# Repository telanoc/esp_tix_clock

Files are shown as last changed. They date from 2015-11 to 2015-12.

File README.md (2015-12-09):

=========================================================================

Module: esp tix clock

Date: 13 November 2015

Author: Pete Cervasio <cervasio@airmail.net>

=========================================================================

This project is a TIX clock running on an ESP-01 module.  Since the I/O
is limited, the two available pins are used for an i2c bus to drive a
port expander.  That handles the 27 LEDs as a 9x3 matrix using a ULN2803
and another transistor for the columns and three transistors to drive
the rows.  The other 4 pins read mostly-useless alarm setting buttons.
If only there was another output to use to drive some kind of alarmy
soundy thing.  Oops.  Perhaps I can modify the code so that it doesn't
send any serial data out, and take over the serial port pins.

So, what's a TIX clock?  Google is your friend, as are Bing and Yahoo.
And Youtube to an extent.

Features:

    ESP-01 module gets time from NTP - All you set is the access point
    & password.  You set the timezone before you compile.  Automatic
    changeover takes over from there.  Just don't move around a lot.
    :)

    Power is +5v, regulated to +3.3 for the ESP-01.  The clock in my
    living room is powered by your generic three-for-a-dollar USB
    power brick.

    Time library used to get NTP.  Modifications were made to make the
    time setting closer to msec accuracy (it's pretty close).  I got
    this from https://github.com/PaulStoffregen/Time if you want the
    original.

    WiFiManager used to auto-connect to the access point, and to set
    up the connection if necessary.  From AlexT
    (https://github.com/tzapu) but custom changes are stored in this
    repository.

    Timezone library (https://github.com/JChristensen/Timezone) used
    to handle automatic DST change.

    Display and Controller boards designed in Eagle 7.4 are included.
    The two boards are shared on Osh Park

        Display: https://www.oshpark.com/shared_projects/UMcsDmIr
     Controller: https://www.oshpark.com/shared_projects/IgKxO56E

    An alarm time can be set, but "oops, I need more pins"... there's
    no alarm output.  So it's not much of a feature after all.  As
	noted above, it should be possible to drop the serial port bits
	and take over those pins to be more gpio.

    A dumb 3d printed case will eventually be available on Tinkercad
    or Thingiverse or somewhere.  The one I have started is close but
    not quite there yet.

Caveats and whatnot:

    This was built using staging release esp8266-1.6.5-1160-gef26c5f

    Soldering SMTs by hand is a pain in the behind when you're older.

    Don't bring pin 9 of the display board to +5v without a current
    limiting resistor or you'll take out the 2n3904.  Don't ask how I
    know that...  the resistor on the control board should have been
    moved.
    
    ... ahh hindsight.

    male Power pins are long out the bottom of the control board to
    allow attaching a header for +5v.  That's how I did it.  If you
    have a better idea, please use it.  :)

Todo:

    Build a nice 3d printed case at the North Richland Hills Library
    Maker Spot.  I can't say enough good things about the most
    important building in NRH (and the highly important room upstairs
    that has all the fun makey bits in it).  If you live around Fort
    Worth, go visit.  It's a "soft" maker space, with no table saws or
    welder or whatnot, but that's what the Dallas maker space is good
    for.  :)

    Revamp the boards to bring out serial data, which would allow for
    setting more parameters and storing them in eeprom, like time zone
    values and stuff like that.

    Move that transistor base resistor to the display board.

Harware BOM:  This should be pretty accurate.

        1 - ESP-01
        1 - mcp23017 (so28w)
        1 - uln2803  (so18w)
        4 - MMBT3904 (sot23-bec)
        2 - BSS138 mosfets (sot-23)
        4 - standard through-hole tactile switches
        1 - AP2112K-3.3 regulator (sot-23-5)
        1 - 10uf 0805 capacitor
        2 - 0.1 uf 0805 capacitor
        1 - 1k 0805 resistor
        6 - 10k 0805 resistor
       27 - 68 ohm 0805 resistors
        3 - AA2214SURSK SMT blue LEDs
        6 - yellow SMT LEDs
        9 - red SMT LEDs
        9 - green SMT LEDs
        1 - 1x2 pin male header (extra long) 
        1 - 1x3 pin male header
        1 - 1x3 pin male header
        1 - 1x3 female header
        1 - 1x2 female header
        1 - 1x9 female header
        1 - 2x4 female header

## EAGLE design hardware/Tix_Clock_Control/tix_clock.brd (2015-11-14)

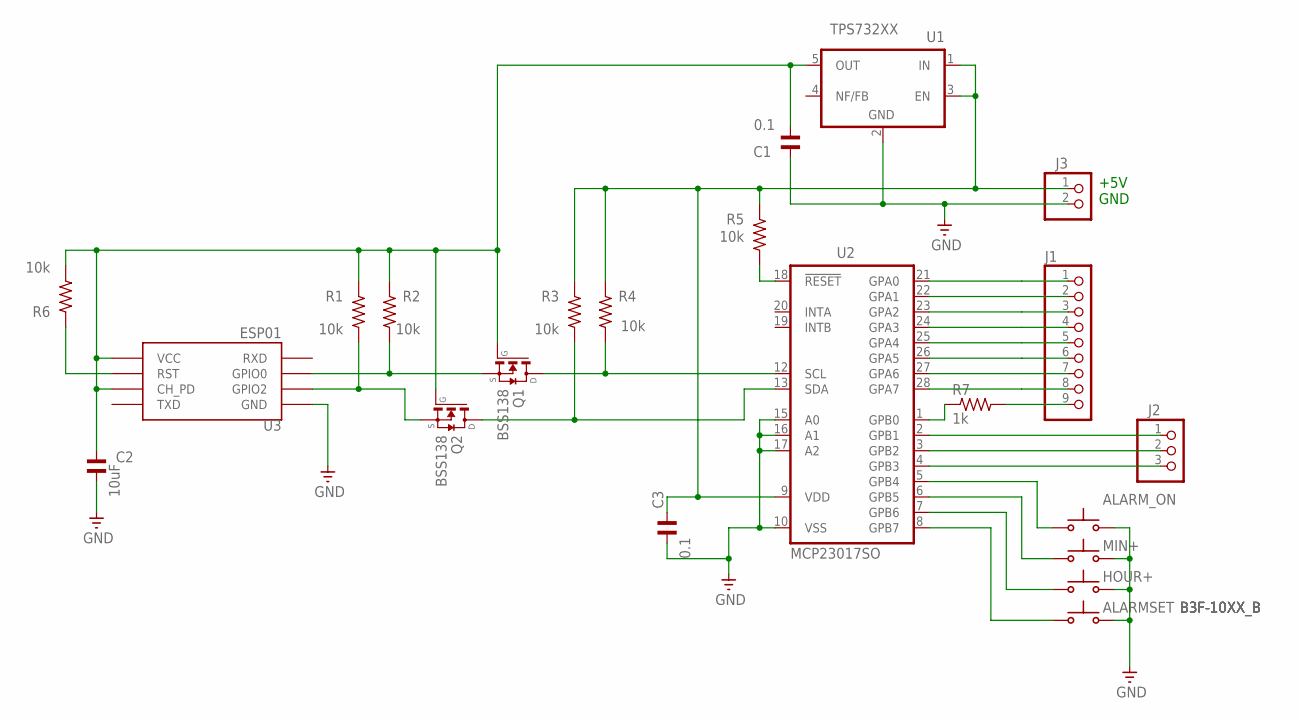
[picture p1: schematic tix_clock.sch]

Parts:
ALARMSET: B3F-10XX_B
ALARM_ON: B3F-10XX_B
C1, C3: 0.1; C0805
C2: 10uF; C0805
HOUR+: B3F-10XX_B
J1: PINHD-1X9; 1X09
J2: PINHD-1X3; 1X03
J3: PINHD-1X2; 1X02
MIN+: B3F-10XX_B
Q1, Q2: BSS138; SOT23
R1, R2, R3, R4, R5, R6: 10k; R0805
R7: 1k; R0805
U1: TPS732XX; SOT23-5
U2: MCP23017SO; SO28W
U3: ESP01

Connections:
GND: ALARMSET.3 (S), ALARMSET.4 (S), ALARM_ON.3 (S), ALARM_ON.4 (S), C1.2, C2.2, C3.2, HOUR+.3 (S), HOUR+.4 (S), J3.2, MIN+.3 (S), MIN+.4 (S), U1.2 (GND), U2.10 (VSS), U2.15 (A0), U2.16 (A1), U2.17 (A2), U3.GND
unnamed: J1.1, U2.21 (GPA0)
unnamed: J1.2, U2.22 (GPA1)
unnamed: J1.3, U2.23 (GPA2)
unnamed: J1.4, U2.24 (GPA3)
unnamed: J1.5, U2.25 (GPA4)
unnamed: J1.6, U2.26 (GPA5)
unnamed: J1.7, U2.27 (GPA6)
unnamed: J1.8, U2.28 (GPA7)
unnamed: J1.9, R7.2
unnamed: J2.1, U2.2 (GPB1)
unnamed: J2.2, U2.3 (GPB2)
unnamed: J2.3, U2.4 (GPB3)
unnamed: ALARM_ON.1, ALARM_ON.2, U2.5 (GPB4)
unnamed: MIN+.1, MIN+.2, U2.6 (GPB5)
unnamed: HOUR+.1, HOUR+.2, U2.7 (GPB6)
unnamed: ALARMSET.1, ALARMSET.2, U2.8 (GPB7)
unnamed: R7.1, U2.1 (GPB0)
unnamed: Q1.3 (D), R4.1, U2.12 (SCL)
unnamed: Q2.3 (D), R3.1, U2.13 (SDA)
unnamed: Q1.2 (S), R2.1, U3.GPIO0
unnamed: Q2.2 (S), R1.1, U3.GPIO2
unnamed: R5.1, U2.18 (!RESET)
unnamed: R6.1, U3.RST
VCC: C1.1, C2.1, Q1.1 (G), Q2.1 (G), R1.2, R2.2, R6.2, U1.5 (OUT), U3.CH_PD, U3.VCC
VDD: C3.1, J3.1, R3.2, R4.2, R5.2, U1.1 (IN), U1.3 (EN), U2.9 (VDD)

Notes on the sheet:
+5V GND

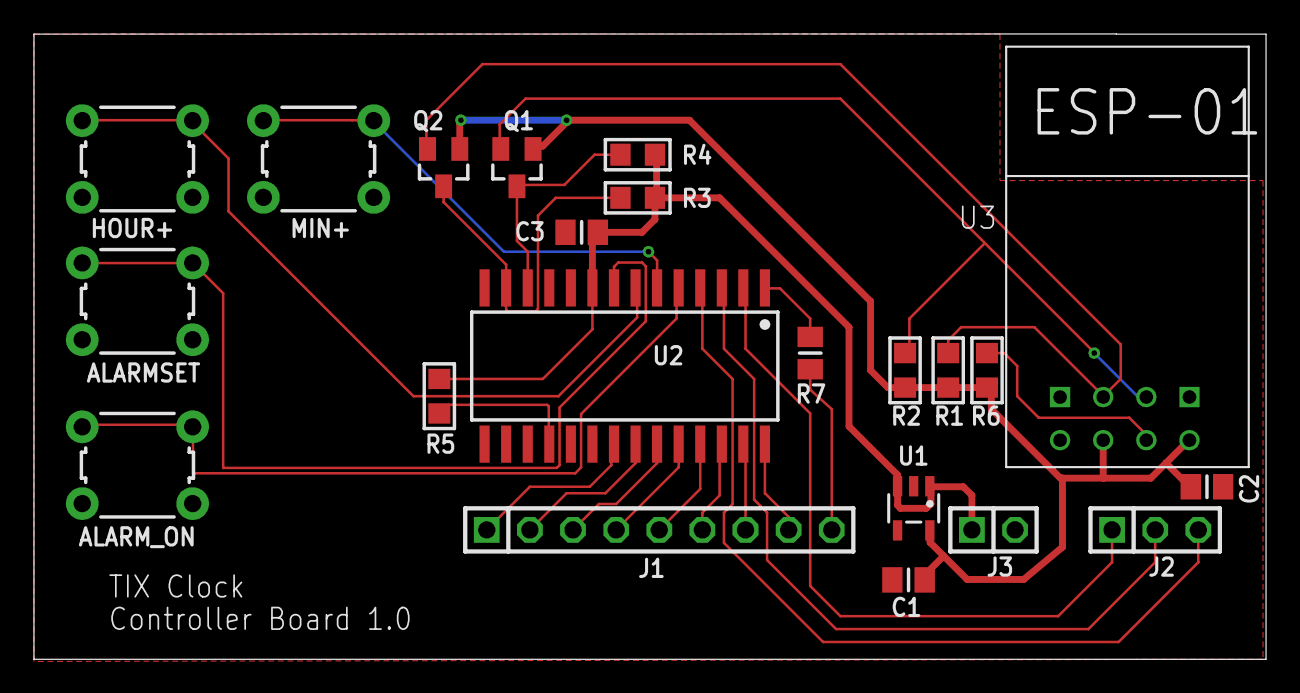
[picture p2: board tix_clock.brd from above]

Board: 2 copper layers, 72.6 x 36.8 mm, 22 parts (0 on the bottom side), 26 nets.

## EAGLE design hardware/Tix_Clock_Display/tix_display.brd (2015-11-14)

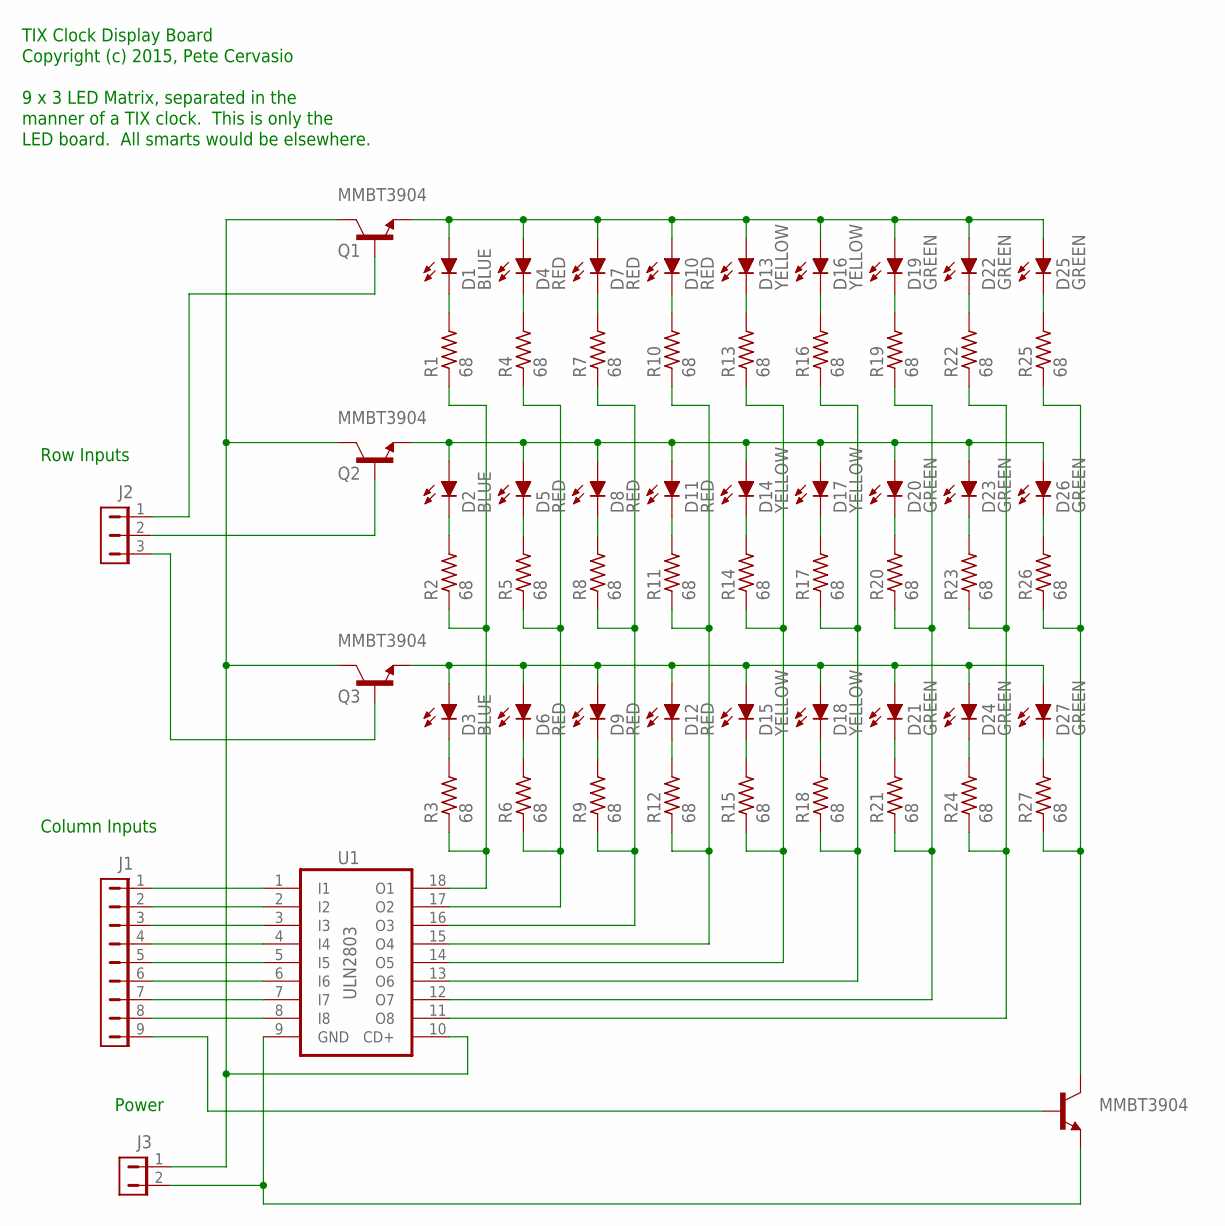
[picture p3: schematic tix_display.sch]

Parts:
D1, D2, D3: BLUE; AA2214SURSK
D4, D5, D6, D7, D8, D9, D10, D11, D12: RED; AA2214SURSK
D13, D14, D15, D16, D17, D18: YELLOW; AA2214SURSK
D19, D20, D21, D22, D23, D24, D25, D26, D27: GREEN; AA2214SURSK
J1: MTA09-100
J2: MTA03-100
J3: MTA02-100
Q1, Q2, Q3, Q4: MMBT3904; SOT23-BEC
R1, R2, R3, R4, R5, R6, R7, R8, R9, R10, R11, R12, R13, R14, R15, R16, R17, R18, R19, R20, R21, R22, R23, R24, R25, R26, R27: 68; M0805
U1: ULN2803; SO18W

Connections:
GND: J3.2, Q4.E, U1.9 (GND)
LEDCOL1: R1.1, R2.1, R3.1, U1.18 (O1)
LEDCOL2: R4.1, R5.1, R6.1, U1.17 (O2)
LEDCOL3: R7.1, R8.1, R9.1, U1.16 (O3)
LEDCOL4: R10.1, R11.1, R12.1, U1.15 (O4)
LEDCOL5: R13.1, R14.1, R15.1, U1.14 (O5)
LEDCOL6: R16.1, R17.1, R18.1, U1.13 (O6)
LEDCOL7: R19.1, R20.1, R21.1, U1.12 (O7)
LEDCOL8: R22.1, R23.1, R24.1, U1.11 (O8)
LEDCOL9: Q4.C, R25.1, R26.1, R27.1
unnamed: D1.A, D4.A, D7.A, D10.A, D13.A, D16.A, D19.A, D22.A, D25.A, Q1.E
unnamed: D2.A, D5.A, D8.A, D11.A, D14.A, D17.A, D20.A, D23.A, D26.A, Q2.E
unnamed: D3.A, D6.A, D9.A, D12.A, D15.A, D18.A, D21.A, D24.A, D27.A, Q3.E
unnamed: D3.C, R3.2
unnamed: D27.C, R27.2
unnamed: J2.1, Q1.B
unnamed: D24.C, R24.2
unnamed: J2.2, Q2.B
unnamed: D21.C, R21.2
unnamed: D18.C, R18.2
unnamed: D15.C, R15.2
unnamed: D12.C, R12.2
unnamed: D9.C, R9.2
unnamed: D6.C, R6.2
unnamed: D2.C, R2.2
unnamed: D5.C, R5.2
unnamed: D8.C, R8.2
unnamed: D11.C, R11.2
unnamed: D14.C, R14.2
unnamed: D17.C, R17.2
unnamed: D20.C, R20.2
unnamed: D23.C, R23.2
unnamed: D26.C, R26.2
unnamed: D1.C, R1.2
unnamed: D25.C, R25.2
unnamed: D22.C, R22.2
unnamed: D19.C, R19.2
unnamed: D16.C, R16.2
unnamed: D13.C, R13.2
unnamed: D10.C, R10.2
unnamed: D7.C, R7.2
unnamed: D4.C, R4.2
unnamed: J2.3, Q3.B
unnamed: J1.1, U1.1 (I1)
unnamed: J1.2, U1.2 (I2)
unnamed: J1.3, U1.3 (I3)
unnamed: J1.4, U1.4 (I4)
unnamed: J1.5, U1.5 (I5)
unnamed: J1.6, U1.6 (I6)
unnamed: J1.7, U1.7 (I7)
unnamed: J1.8, U1.8 (I8)
unnamed: J1.9, Q4.B
VCC: J3.1, Q1.C, Q2.C, Q3.C, U1.10 (CD+)

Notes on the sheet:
Row Inputs
Column Inputs
Power
TIX Clock Display Board Copyright (c) 2015, Pete Cervasio 9 x 3 LED Matrix, separated in the manner of a TIX clock. This is only the LED board. All smarts would be elsewhere.

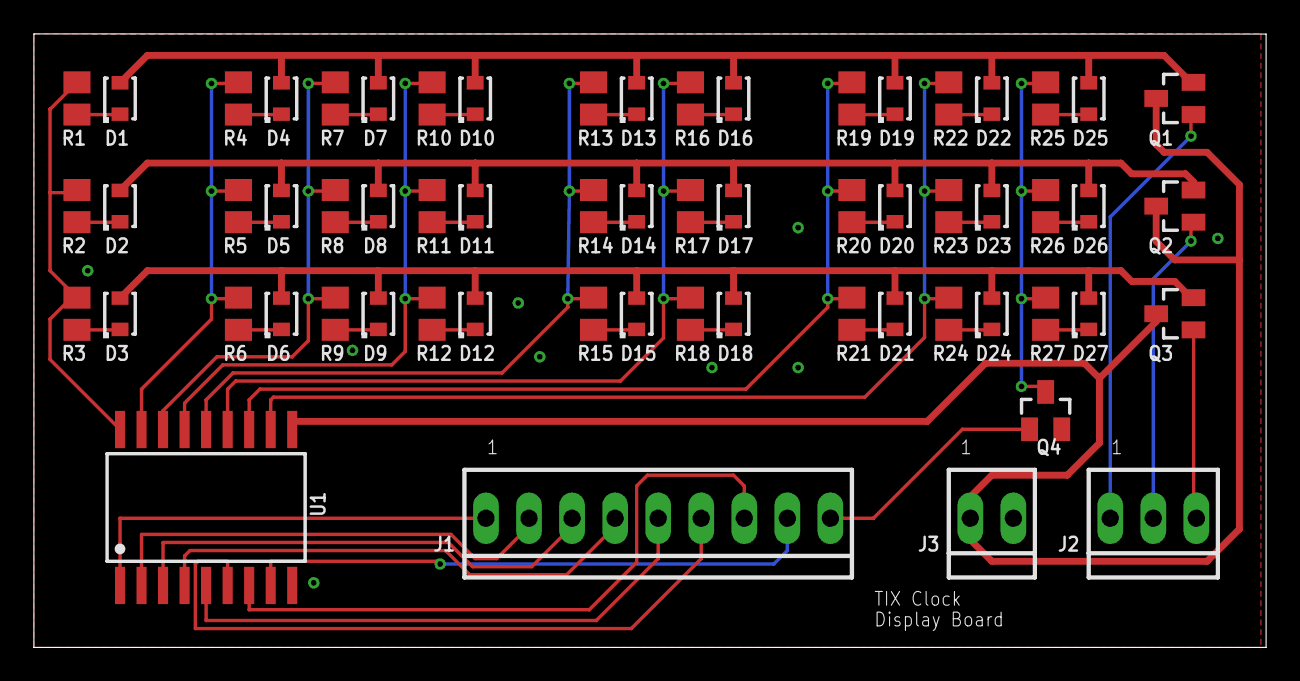
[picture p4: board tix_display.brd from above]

Board: 2 copper layers, 72.7 x 36.2 mm, 62 parts (0 on the bottom side), 53 nets.

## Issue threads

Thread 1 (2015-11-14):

Rev 2 display board needed

telanoc, 2015-11-14:
Existing clock is nice, but tiny.  Need to do a 2nd display board that doesn't have the LEDs mounted, but rather through-holes so external front-panelly kind of LEDs can be attached, for a big TIX clock.

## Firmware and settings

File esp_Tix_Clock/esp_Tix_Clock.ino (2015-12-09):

/*
 * =======================================================================
 * ESP-01 TIX clock
 *
 * Author: Pete Cervasio <cervasio@airmail.net>
 * Date  : 21 SEP 2015
 * 
 * Module: This is a TIX clock using the ESP8266 WiFi chip, in the
 * form of the ESP-01 module.  Since there are only two digital
 * I/O pins available, the options for controlling 27 LEDs are
 * somewhat limited.
 *
 * In this case, we are talking to an MCP23017 16 bit port expander.  It
 * is accessed using gpio0 as the clock line and gpio2 as the data line.
 * The base address of 0x20 is being used.
 * 
 * Bits 0-7 of port A, and bit 0 of port B are being used as column bits
 * while bits 1, 2 and 3 of port B are being used as the row bits.  As
 * there is no PWM control, there is no brightness adjustment.
 * 
 * Bits 4-7 of port B are used as inputs to read 4 switches.  Alarm On
 * toggle, Alarm Set, Alarm Hour+ and Alarm Minute+.
 *
 * Clock logic:
 *
 * The time is retrieved via NTP to 'pool.us.ntp.org'.  A new server is
 * requested any time no response is received from the old server.  The 
 * time server is requeried after one minute at start, which changes to
 * to once per five minutes * successful queries (up to 30 minutes).
 * This is a simple NTP app that doesn't deal with drift.  Whatever the
 * ntp server says the time is, that's what is displayed.
 * 
 * The Time.cpp library is slightly modified to provide a way to set the
 * initial millisecond of the time.  The sync provider callback uses a
 * unsigned long * msec parameter to pass that in.  This makes the clock
 * setting very much more accurate than without, where it can be up to
 * 999 msec off.  When comparing to the time displayed by my NTP synced 
 * Linux desktop, the time changes appear simultaneous.
 * 
 * The WiFiManager library is used to make WiFi setup painless.  The
 * access point and password get stored in eeprom.  If the device can't
 * connect at startup, it sets up a web server on 192.168.4.1 which can
 * be connected to and used to set up the wifi parameters.  This was
 * also modified to 
 * 
 * The Timezone library works with Time and makes DST painless.
 * 
 * At power on, after display test if AlarmSet, Hour+ and Min+ are down, 
 * the current wifi settings are cleared.  Noted by a LED chase display.
 * 
 * TODO: Save alarm time to EEPROM
 *       Work out how to have an alarm beeper (out of pins!)
 *
 * TODO DONE:
 *
 *      Code is at https://github.com/telanoc/esp_tix_clock
 *
 *      Boards at https://www.oshpark.com/shared_projects/UMcsDmIr
 *                https://www.oshpark.com/shared_projects/IgKxO56E
 * 
 * ----------------------------------------------------------------------
 */

#include <ESP8266WiFi.h>        // https://github.com/esp8266/Arduino
#include <EEPROM.h>
#include <ESP8266WebServer.h>
#include <DNSServer.h>
#include <WiFiManager.h>        // https://github.com/tzapu/WiFiManager
#include <WiFiUdp.h>
#include <Wire.h>

// NOTE: Time library modified to pass in partial seconds from UDP packet receive
#include <Time.h>
#include <Timezone.h>

#define TIX_DEBUG

// ESP pins we will use to talk to the i2c bus.  Clock is on
// GPIO0 and data is on GPIO2.
#define SCL_PIN 0
#define SDA_PIN 2

// Address of the MCP23017 i2c port expander on the i2c bus
// This project uses the base address.
#define mcp23017 0x20

// MCP23017 control register definitions
#define REG_MCP_IODIRA   0x00
#define REG_MCP_IODIRB   0x01
#define REG_MCP_IPOLA    0x02
#define REG_MCP_IPOLB    0x03
#define REG_MCP_GPINTENA 0x04
#define REG_MCP_GPINTENB 0x05
#define REG_MCP_DEFVALA  0x06
#define REG_MCP_DEFVALB  0x07
#define REG_MCP_INTCONA  0x08
#define REG_MCP_INTCONB  0x09
#define REG_MCP_IOCONA   0x0A
#define REG_MCP_IOCON    REG_MCP_IOCONA
#define REG_MCP_IOCONB   0x0B
#define REG_MCP_GPPUA    0x0C
#define REG_MCP_GPPUB    0x0D
#define REG_MCP_INTFA    0x0E
#define REG_MCP_INTFB    0x0F
#define REG_MCP_INTCAPA  0x10
#define REG_MCP_INTCAPB  0x11
#define REG_MCP_GPIOA    0x12
#define REG_MCP_GPIOB    0x13
#define REG_MCP_OLATA    0x14
#define REG_MCP_OLATB    0x15

WiFiManager wifi;
unsigned int localPort = 12525;

IPAddress timeServerIP;
const char *ntpServerName = "us.pool.ntp.org";

WiFiUDP udp;

// If this was a good clock, it'd have every timezone defined and let you pick
// which one you wanted during access point setup.  Guess what... this clock
// isn't 100% good.

//US Central Time Zone (Chicago, Dallas, etc)
// Format: Name, which, day of week, month, hour to change, new offset from utc
TimeChangeRule usCDT = {"CDT", Second, dowSunday, Mar, 2, -300};
TimeChangeRule usCST = {"CST", First, dowSunday, Nov, 2, -360};
Timezone myTZ(usCDT, usCST);
TimeChangeRule *tcr;

int lastHour = -1;
int lastMin  = -1;

time_t lastnow = 0;
time_t utc = 0;
time_t local = 0;

int alarm_hour = 12;
int alarm_minute = 34;

// State of ALARM_SET button
bool showing_alarm = false;

// some globals to store our last hour+/min+ button states
bool lastminp = false;
bool lasthourp = false;

// After read/shift, these are the button bits
#define BIT_ALARM_ON      0
#define BIT_MINUTE_PLUS   1
#define BIT_HOUR_PLUS     2
#define BIT_ALARM_SET     3

// Clock display related time values
#define ROWCOUNT 3
#define COLCOUNT 9

// Bits for the columns of each of the 3 rows
unsigned int LedWords[ROWCOUNT] = { 0, 0, 0 };
// values or'd to turn on row driver transistors
unsigned int rowbits[ROWCOUNT] = { 0x0200, 0x0400, 0x0800 };

unsigned long last_ms = 0;
unsigned long last_update = 0;

int ntp_good_count = 0;

int cur_row = 0;

// These should really be named i2c_read... and i2c_write... as they're
// not specific to a gpio port expander.  One day, when I feel like it.
word gpio_read_word(int address, int regnum);
int  gpio_read_byte(int address, int regnum);
void gpio_write_word(int address, int regnum, word data);
void gpio_write_byte(int address, int regnum, byte data);

// initializes the mcp32017 registers for our purposes
void init_mcp23017(int address);
void mcp_write(int ab, byte value);
void mcp_write2(word value);
byte mcp_read(void);


// Modified Time library callback.  Return time and write millisec of the time
// to *msec.
time_t getNtpTime(unsigned long * msec);

unsigned long sendNTPpacket(IPAddress & address);


//=========================================================================
// Routine: fill_clock_dots
//-------------------------------------------------------------------------
// Parameters:
//   rows    : Number of rows to use in the matrix
//   cols    : How many columns to use in the matrix
//   numdots : How many random values to set to true
//   offset  : Starting column in the matrix
//-------------------------------------------------------------------------
// Purpose: Sets [numdots] random TIX digit LEDs into [cols] colums at an
// offset of [offset].
//=========================================================================
void fill_clock_dots(int rows, int cols, int numdots, int offset)
{
  int row, col;
  int count = 0;

  // Shortcut - if setting all on, just set them all on
  if (numdots >= (rows * cols)) {
    for (row = 0; row < rows; row++) {
      for (col = 0; col < cols; col++) {
        bitSet(LedWords[row], col + offset);
      }
    }
    return;
  }

  while (count < numdots) {
    row = random(rows);
    col = random(cols);
    if (bitRead(LedWords[row], col + offset) == 0) {
      bitSet(LedWords[row], col + offset);
      count++;
    }
  }
}

//=========================================================================
// Routine: update_displayed_time
//-------------------------------------------------------------------------
// Parameters:
//   when : The time_t value to load into the Tix clock LED matrix
//-------------------------------------------------------------------------
// Purpose:  Update the LedWords[] array with proper information.  Will be
// called every time the hours or minutes change, and whenever a new set
// of random leds is wanted (every 5 seconds at initial writing)
//=========================================================================
void update_displayed_time (time_t when)
{  
  LedWords[0] = LedWords[1] = LedWords[2] = 0;

  int hh = hour(when);
  int mm = minute(when);

  fill_clock_dots (3, 1, hh / 10, 0);
  fill_clock_dots (3, 3, hh % 10, 1);
  fill_clock_dots (3, 2, mm / 10, 4);
  fill_clock_dots (3, 3, mm % 10, 6);
}

//=========================================================================
// Routine: update_displayed_alarm
//-------------------------------------------------------------------------
// Parameters:
//   none
//-------------------------------------------------------------------------
// Purpose:  Update the LedWords[] array with the alarm time.  
//=========================================================================
void update_displayed_alarm()
{
  LedWords[0] = LedWords[1] = LedWords[2] = 0;  /* never forget to do this */
  
  fill_clock_dots (3, 1, alarm_hour / 10, 0);
  fill_clock_dots (3, 3, alarm_hour % 10, 1);
  fill_clock_dots (3, 2, alarm_minute / 10, 4);
  fill_clock_dots (3, 3, alarm_minute % 10, 6);
}


//=========================================================================
// Routine: show_time_row
//-------------------------------------------------------------------------
// Parameters: 
//   row: Which row of data to send, obviously
//-------------------------------------------------------------------------
// Purpose: Send out a row of data to the multiplexed LED array.
//=========================================================================
void show_time_row(int row)
{
  mcp_write2(LedWords[row] | rowbits[row]);
}


//=========================================================================
// Routine: setup
//-------------------------------------------------------------------------
// Parameters:
//   none
//-------------------------------------------------------------------------
// Purpose: Initialization code for the clock.
//=========================================================================
void setup()
{
  // put your setup code here, to run once:  (okay, thanks Arduino)
  
  Serial.begin(115200);
  Serial.println();
  Serial.println("-----------------------------------------------");
  Serial.println("Initializing MCP23017 i/o expander");

  Wire.begin(SDA_PIN, SCL_PIN);
  init_mcp23017(mcp23017);
  mcp_write2(0);

  Serial.println("Starting LED test");
  for (int b = 0; b < COLCOUNT; b++) {
    // This should use math and ROWCOUNT, not hard coding
    mcp_write2((1 << b) | rowbits[0] | rowbits[1] | rowbits[2] );
    delay (200);
  }
  // This bit too.
  mcp_write2(0x1ff | rowbits[0] | rowbits[1] | rowbits[2]);
  delay (1000);
  mcp_write2(0);
  delay (100);
  
  word btns = mcp_read() >> 4;
  if (btns == 0x0e) {
    // Hour/Min set and Alarm Set pressed at startup - clear Wifi data
    wifi.resetSettings();
    // And do a dance on the LEDs so I know it happened.
    for (int i = 0; i < 5; i++) {
      for (int b = 0; b < COLCOUNT; b++) {
        mcp_write2((1 << b) | rowbits[1] );
        delay (100);
      }
      for (int b = COLCOUNT - 2; b > 0; b--) {
        mcp_write2((1 << b) | rowbits[1] );
        delay (100);
      }
    }      
    mcp_write2(0);
  }

  Serial.println("Initializing WiFi connection");

  // WiFiManager fetches ssid and pass from eeprom and tries to connect
  // if it does not connect it starts an access point with the specified name
  // (here "Tix_Clock") and goes into a blocking loop awaiting configuration
  wifi.autoConnect("Tix_Clock");
  yield();

  // We must be connected now.
  Serial.println("WiFi connected");
  Serial.print("IP address: ");
  Serial.println(WiFi.localIP());
  yield();

  //get a random server from the pool
  WiFi.hostByName(ntpServerName, timeServerIP); 
  Serial.print ("Ntp server: ");
  Serial.println (timeServerIP);
  yield();
  
  Serial.println("Starting UDP");
  udp.begin(localPort);
  Serial.print("Local port: ");
  Serial.println(udp.localPort());

  yield();
  setSyncInterval (60);
  setSyncProvider(getNtpTime);

  while (timeStatus() != timeSet) {
    mcp_write2(0x1ff | rowbits[0] | rowbits[2]);
    delay (500);
    setSyncProvider(getNtpTime);
  }
  mcp_write2(0);
  
  delay (200);
  Serial.println("TiX clock initialization complete.  Enjoy your time.");
  Serial.println("----------------------------------------------------");
  Serial.println();

  // initialize the "last time" value
  last_ms = millis();
}


//=========================================================================
// Routine: loop
//-------------------------------------------------------------------------
// Parameters:
//-------------------------------------------------------------------------
// Purpose: "main" program loop.  Called over and over repeatedly.
//=========================================================================
void loop()
{
  unsigned long curr_ms = millis();

  // update the clock parameters every 50 msec.  This also
  // takes care of our switch debouncing while we're at it.
  
  if (curr_ms - last_update > 50)
  {
    // read button bits
    word btns = mcp_read() >> 4;

    if (showing_alarm != bitRead(btns, BIT_ALARM_SET)) {
      showing_alarm = bitRead(btns, BIT_ALARM_SET);
      if (showing_alarm) {
        // Transfer alarm time to display bits
        update_displayed_alarm(); 
      } else {
        // We must have let go of the button... force the clock
        // logic to immediately update the LEDs
        lastHour = -1;
      }
    }
    
    if (showing_alarm) {
      
      // Alarm_Set button down.  Handle adjust buttons.  The
      // alarm time only gets random LEDs when the alarm time
      // changes, not every {x} seconds.
      
      if (lastminp != bitRead (btns, BIT_MINUTE_PLUS)) {
        lastminp = bitRead (btns, BIT_MINUTE_PLUS);
        if (lastminp) {
          alarm_minute = (alarm_minute + 1) % 60;
          update_displayed_alarm();
        }
      }

      if (lasthourp != bitRead (btns, BIT_HOUR_PLUS)) {
        lasthourp = bitRead (btns, BIT_HOUR_PLUS);
        if (lasthourp) {
          alarm_hour = (alarm_hour + 1) % 24;
          update_displayed_alarm();
        }
      }
    } else {
      
      // AlarmSet button not down, deal with display of the current time
      
      local = myTZ.toLocal(now(), &tcr);
      int aHour = hour(local);
      int aMin  = minute(local);
      int aSec  = second(local);
      if ((aHour != lastHour) || (aMin != lastMin) || (aSec % 5 == 0 && lastnow != local) ) {   
        update_displayed_time (local);
        // Only print serial time every 15 seconds
        if (aSec % 15 == 0) 
          printTime (local, tcr->abbrev); 
  
        lastnow = local;
        lastHour = aHour;
        lastMin = aMin;
      }
    }
    last_update = curr_ms;
  }

  // update the display all the time
  show_time_row(cur_row);
  cur_row = (cur_row + 1) % ROWCOUNT;
  delay (5);
  mcp_write2(0);  
}


//=========================================================================
// Routine: init_mcp23017
//-------------------------------------------------------------------------
// Parameters:
//   address: bus address of the device on the i2c bus
//-------------------------------------------------------------------------
// Purpose: Configure mcp23017 properly for our application
//=========================================================================
void init_mcp23017(int address)
{
    // Init IO Config - set the following bits
    //    INTPOL (bit 1) = 1    (int output active-high)
    //    ODR    (bit 2) = 0    (use active output)
    //    MIRROR (bit 6) = 1    (both INT pins the same value)

    // 12 OCT 2015: [PWC] - don't need these in this project.
    //byte iocon = (1 << 1) | (1 << 6);
    //gpio_write_byte (address, REG_MCP_IOCON, iocon);
    //gpio_write_byte (address, REG_MCP_IOCONB, iocon);

    // Set A and half of B as outputs
    gpio_write_byte(address, REG_MCP_IODIRA, 0x00);
    gpio_write_byte(address, REG_MCP_IODIRB, 0xf0);

    // Force normal polarity
    gpio_write_word(address, REG_MCP_IPOLA, 0xffff);
    //gpio_write_byte(address, REG_MCP_IPOLB, 0xff);

    // input defaults
    gpio_write_word (address, REG_MCP_DEFVALB, 0xF0);

    // enable 100k pullups on switch inputs, please
    gpio_write_byte (address, REG_MCP_GPPUB, 0xf0);

}

//=========================================================================
// Routine: gpio_read_word
//-------------------------------------------------------------------------
// Parameters:
//-------------------------------------------------------------------------
// Purpose: Read 16 bits of information from expander chip input ports
//=========================================================================
word gpio_read_word(int address, int regnum)
{
    int data = 0;

    //  Send input register address
    Wire.beginTransmission(address);
    Wire.write(regnum);
    Wire.endTransmission();

    //  Connect to device and request two bytes
    Wire.beginTransmission(address);
    Wire.requestFrom(address, 2);

    if (Wire.available()) {
        data = Wire.read();
    }
    if (Wire.available()) {
        data |= Wire.read() << 8;
    }

    Wire.endTransmission();

    return data;
}

//=========================================================================
// Routine: gpio_read_word
//-------------------------------------------------------------------------
// Parameters:
//-------------------------------------------------------------------------
// Purpose: Read a byte from any port expander chip register
//=========================================================================
int gpio_read_byte(int address, int regnum)
{
    int data = 0;

    //  Send input register address
    Wire.beginTransmission(address);
    Wire.write(regnum);
    Wire.endTransmission();

    //  Connect to device and request two bytes
    Wire.beginTransmission(address);
    Wire.requestFrom(address, 1);

    if (Wire.available()) {
        data = Wire.read();
    }

    Wire.endTransmission();

    return data;
}

//=========================================================================
// Routine: gpio_write_word
//-------------------------------------------------------------------------
// Parameters:
//-------------------------------------------------------------------------
// Purpose: Write 16 bits to the port expander digital outputs
//=========================================================================
void gpio_write_word(int address, int regnum, word data)
{
    //  Send output register address
    Wire.beginTransmission(address);
    Wire.write(regnum);

    //  Connect to device and send two bytes
    Wire.write(0xff & data);    //  low byte
    Wire.write(data >> 8);      //  high byte

    Wire.endTransmission();
}


//=========================================================================
// Routine: gpio_write_byte
//-------------------------------------------------------------------------
// Parameters:
//-------------------------------------------------------------------------
// Purpose: Write a byte to any port expander register
//=========================================================================
void gpio_write_byte(int address, int regnum, byte data)
{
    //  Send output register address
    Wire.beginTransmission(address);
    Wire.write(regnum);

    //  Connect to device and send byte
    Wire.write(0xff & data);

    Wire.endTransmission();
}


//=========================================================================
// Routine: mcp_write()
//-------------------------------------------------------------------------
// Parameters:
//   ab: 0 = port a, 1 = port b
//   value: what value to write
//-------------------------------------------------------------------------
// Purpose: Write a byte value to the GPIO outputs, either port A or B.
//=========================================================================
void mcp_write(int ab, byte value)
{
    gpio_write_byte(mcp23017, REG_MCP_GPIOA + ab, value);
}

//=========================================================================
// Routine: mcp_write2()
//-------------------------------------------------------------------------
// Parameters:
//   value: 16 bit word value to write
//-------------------------------------------------------------------------
// Purpose: Write to both GPIO outputs at once.
//=========================================================================
void mcp_write2(word value)
{
    gpio_write_word(mcp23017, REG_MCP_GPIOA, value);
}


//=========================================================================
// Routine: mcp_read()
//-------------------------------------------------------------------------
// Parameters:
//   none
//-------------------------------------------------------------------------
// Purpose: Read port B data from the mcp 23017 port expander.  
//=========================================================================
byte mcp_read(void)
{
  return gpio_read_byte (mcp23017, REG_MCP_GPIOB);
}


//=========================================================================
// Routine: printTime
//-------------------------------------------------------------------------
// Parameters:
//   t : Time to display
//  *tz: timezone
//-------------------------------------------------------------------------
// Purpose: Send time to the serial port
//=========================================================================
//Function to print time with time zone
void printTime(time_t t, char *tz)
{
    sPrintI00(hour(t));
    sPrintDigits(minute(t));
    sPrintDigits(second(t));
    Serial.print(' ');
    Serial.print(dayShortStr(weekday(t)));
    Serial.print(' ');
    sPrintI00(day(t));
    Serial.print(' ');
    Serial.print(monthShortStr(month(t)));
    Serial.print(' ');
    Serial.print(year(t));
    Serial.print(' ');
    Serial.print(tz);
    Serial.println();
}
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

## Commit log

2015-11-14 Initial import of project files
    [tix_clock.brd, tix_clock.sch, tix_display.brd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]
2015-11-14 add url for osh park boards

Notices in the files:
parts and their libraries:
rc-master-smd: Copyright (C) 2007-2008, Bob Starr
